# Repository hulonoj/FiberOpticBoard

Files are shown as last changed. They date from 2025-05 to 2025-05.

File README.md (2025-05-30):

# Fiber Optic Based Signal Extender

A high-speed hardware system designed to transmit and replicate electrical signals over long distances using fiber optics with minimal latency.



## Overview

This project consists of two custom PCB systems designed for high-speed signal replication across fiber:

- **Transmitter/Receiver Board:** FPGA-based PCB for protocol-agnostic electrical signal replication over fiber with ~30 ns latency.
- **Motor Controller Board:** STM32-based H-Bridge driver interfaced via I2C through the fiber optic system.

The design demonstrates a full end-to-end communication system without electrical coupling, ideal for applications where noise isolation or long-distance communication is required. This was my capstone project for my Advanced Embedded Systems course at the University of Michigan, and was worked on by a team of five. I contributed heavily and mainly to the hardware development and testing, while collaborating closely with teammates on software and system integration and validation.

## Features

- Custom fiber optic communication protocol with latency < 30 ns
- Supports arbitrary digital signal formats (protocol-agnostic)
- Isolated end-to-end data replication
- STM32 motor controller with I2C command input
- Integrated H-Bridge for direct motor control

## Photos

Fiber Optic Board mounted on top of a motor controller board.

Half-Assembled Fiber Optic Board



Schematic

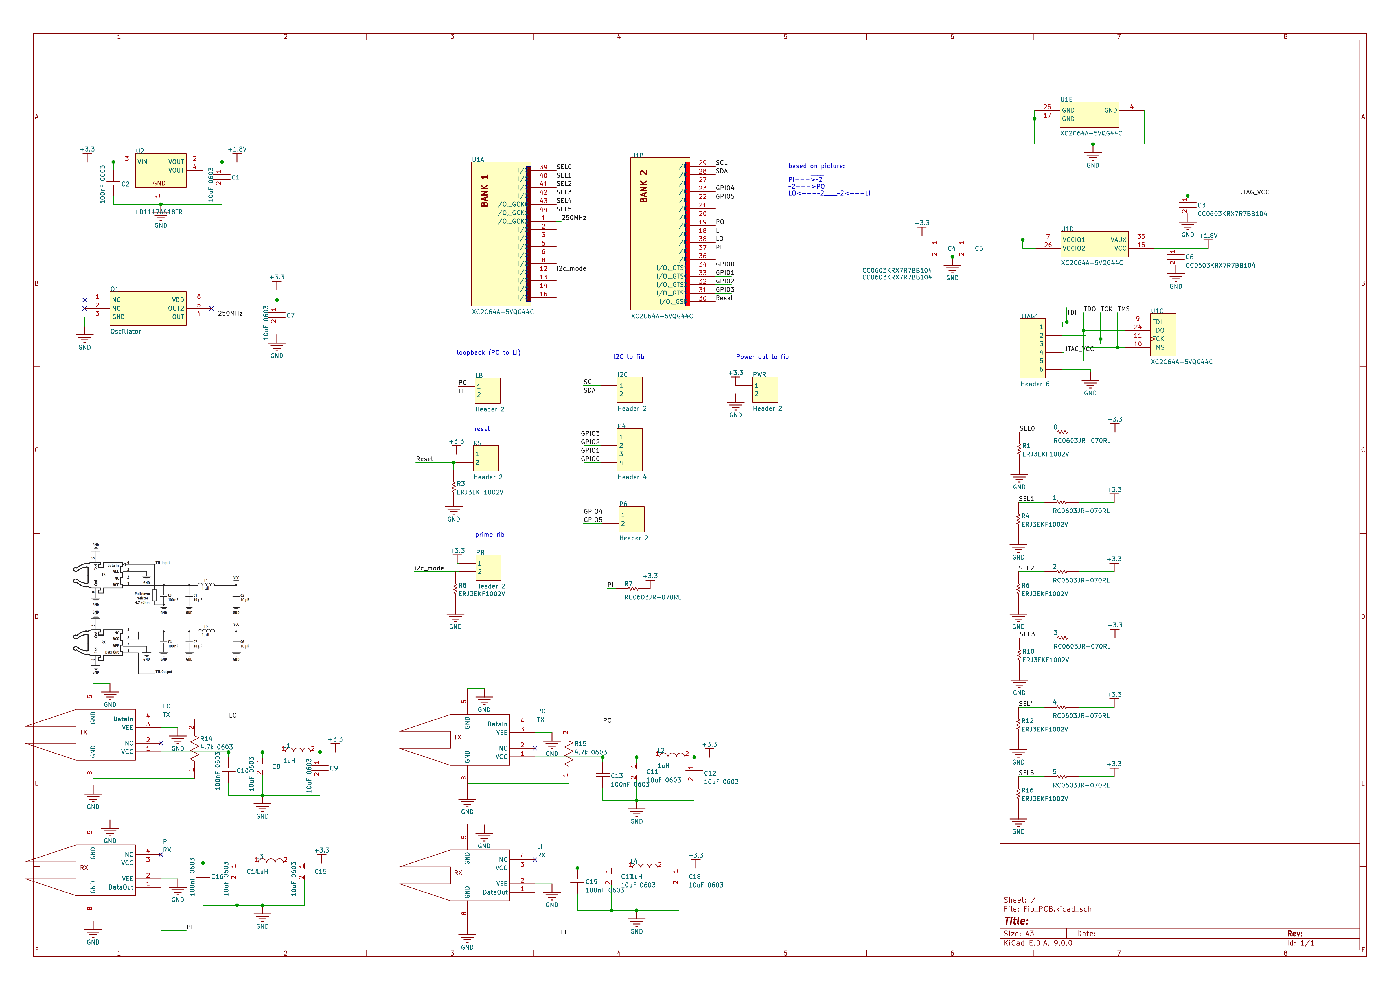
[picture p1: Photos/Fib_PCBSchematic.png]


Layout

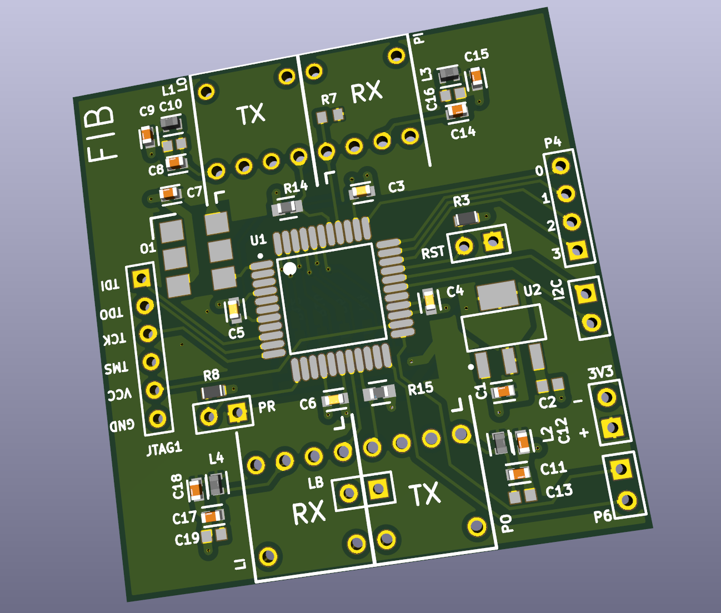
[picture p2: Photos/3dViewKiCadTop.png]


## Poster Describing Project
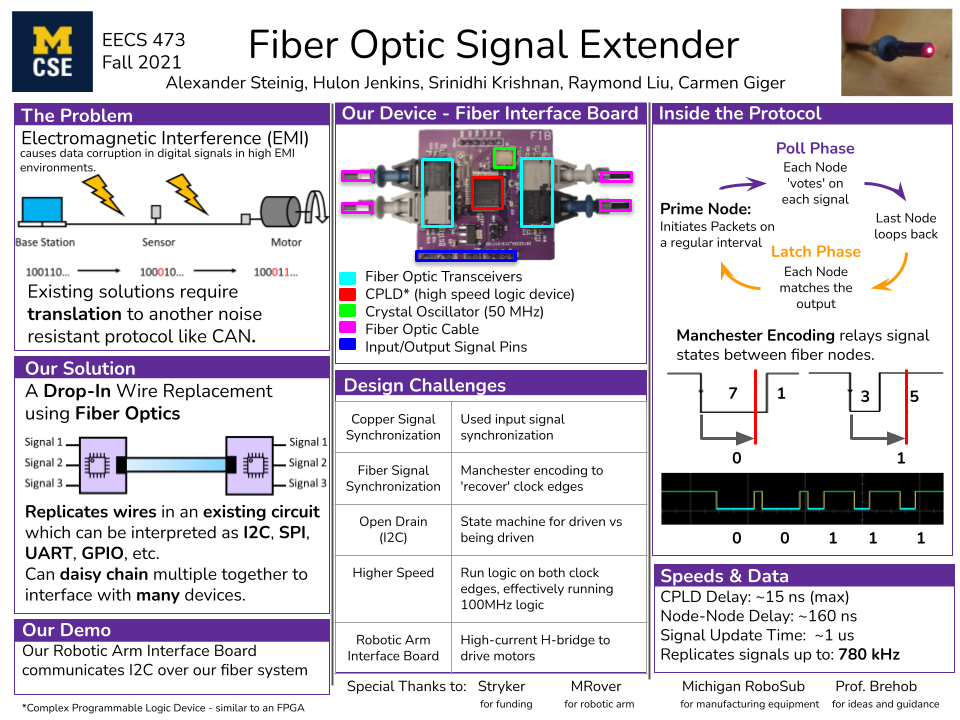
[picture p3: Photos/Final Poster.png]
Poster


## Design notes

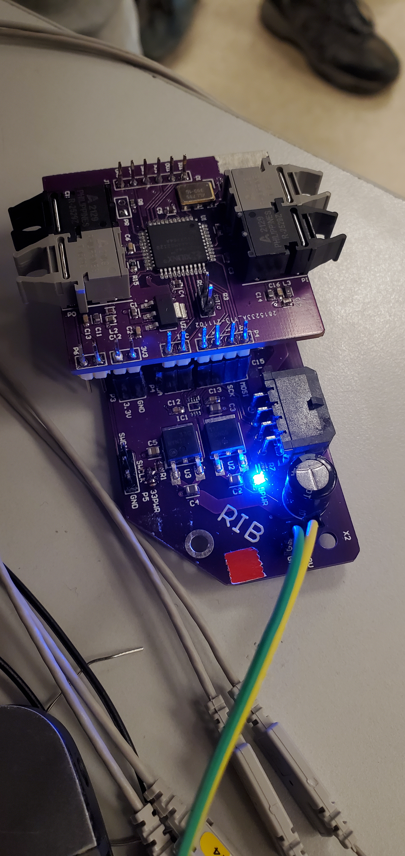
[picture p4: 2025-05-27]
Photos/FiberBoardMounted.jpg

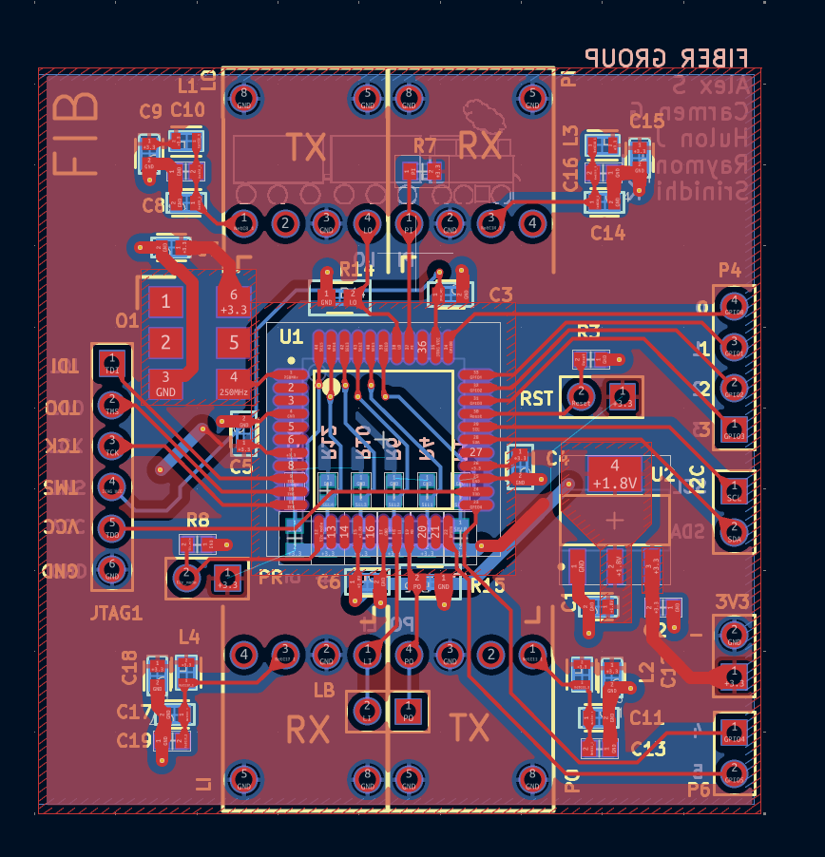
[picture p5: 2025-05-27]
Photos/LayoutKiCad.png

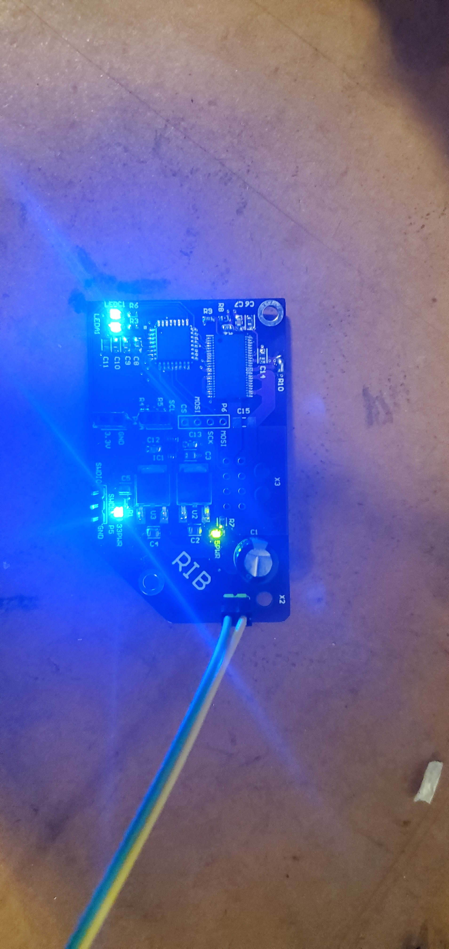
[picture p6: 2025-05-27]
Photos/MotorboardLightsOn.jpg

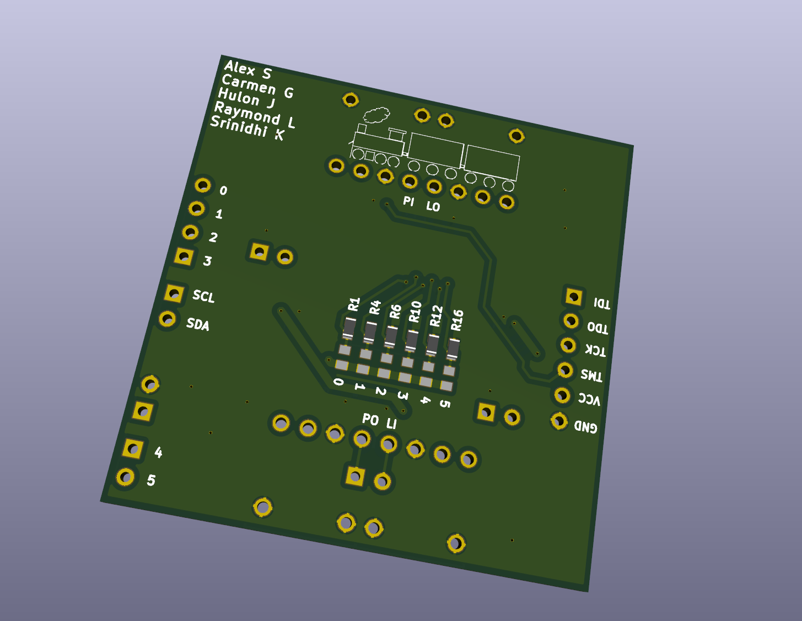
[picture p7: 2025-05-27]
Photos/3dViewKiCadBottom.png

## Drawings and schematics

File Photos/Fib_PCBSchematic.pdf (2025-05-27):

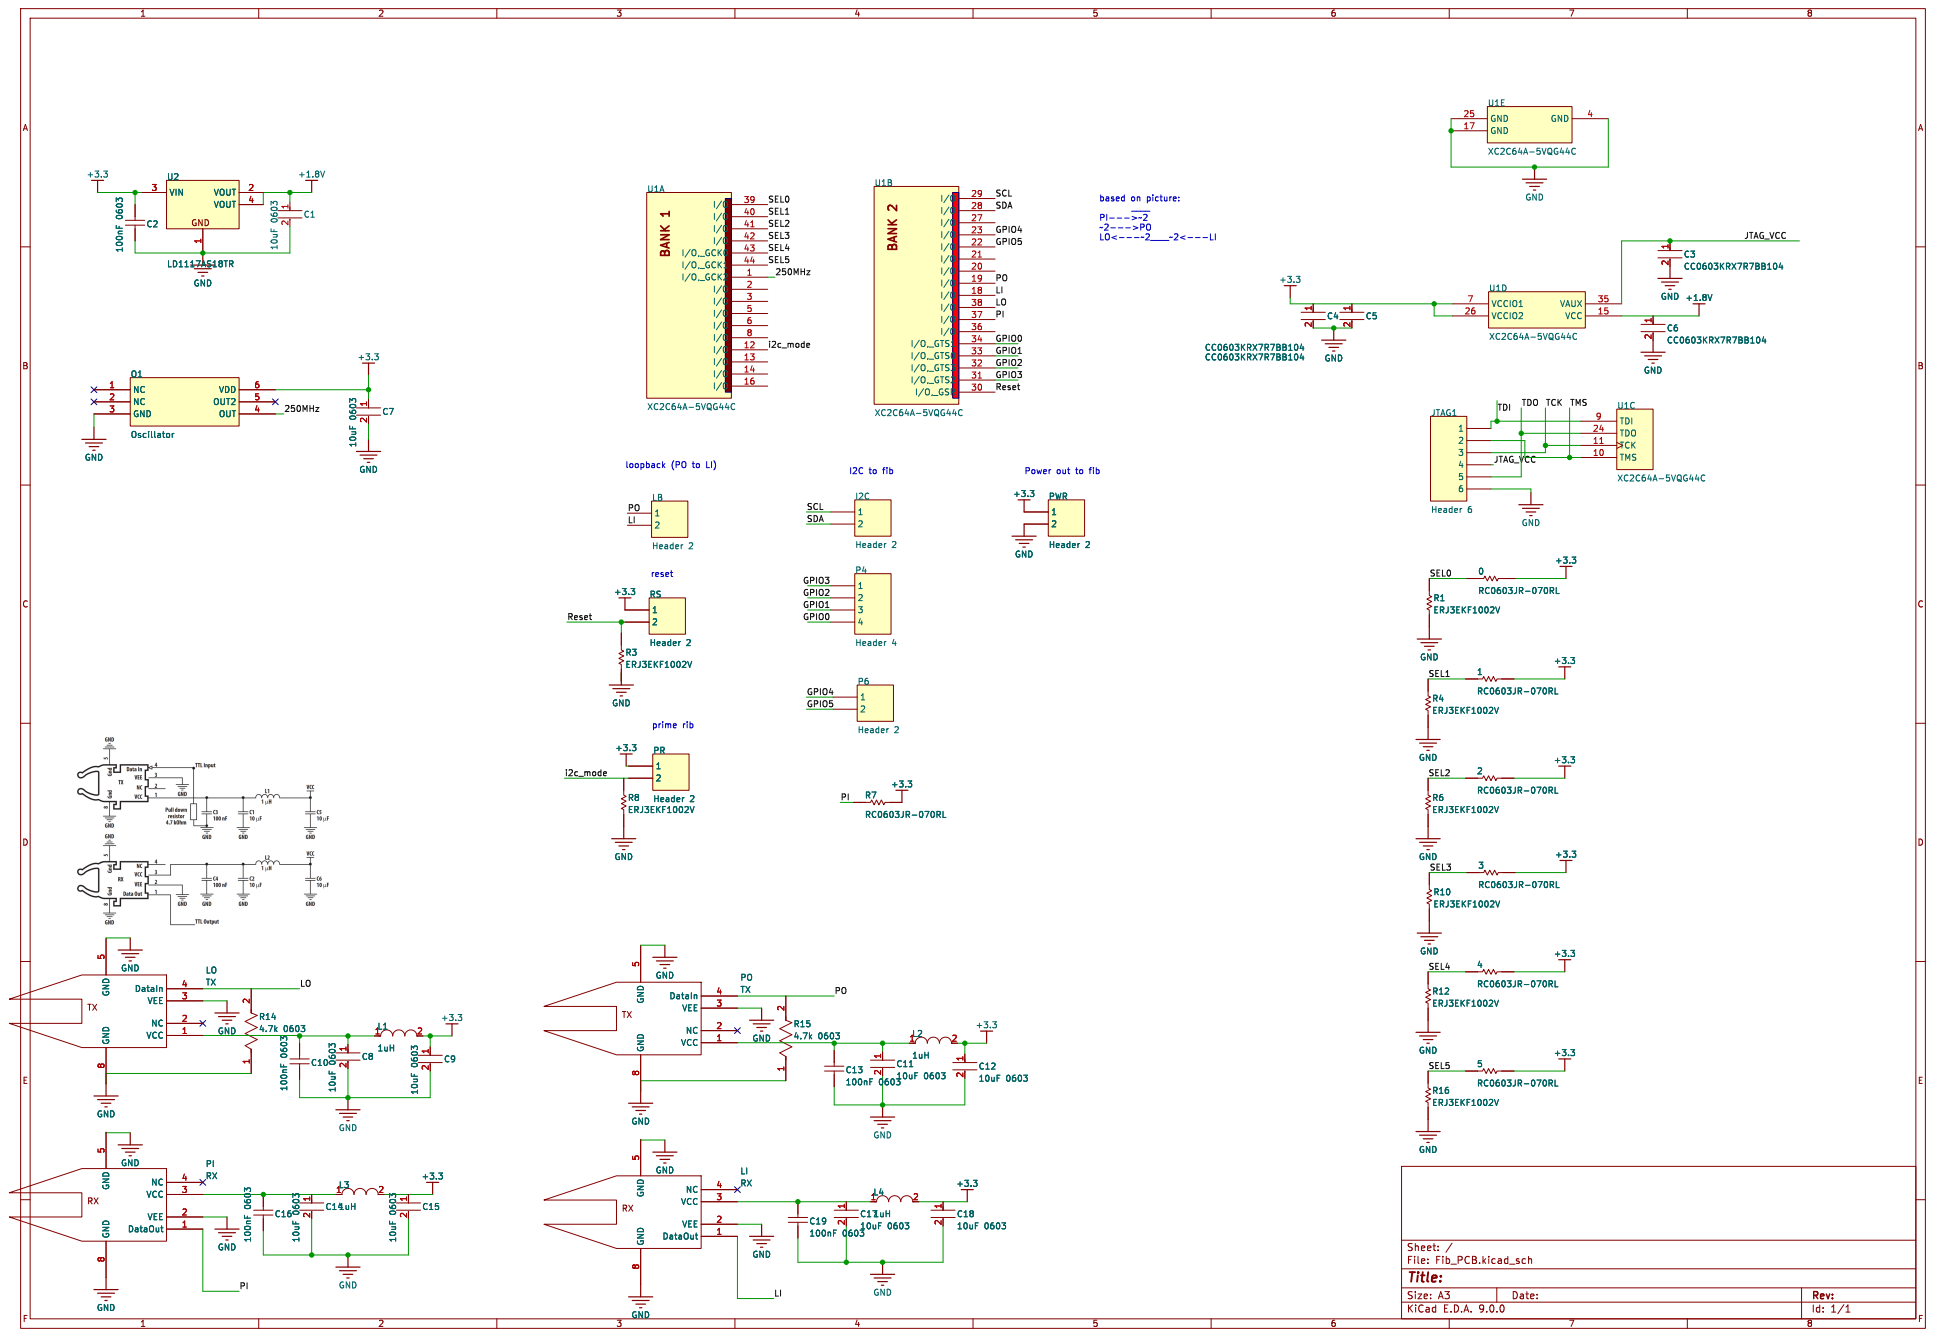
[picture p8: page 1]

1 VOUT 2 VOUT 4 GND O1 Oscillator NC 1 NC 2 GND 3 VDD 6 OUT2 5 OUT 4 GND

8 DataIn 4 VEE 3 NC 2 VCC 1 GND GND

8 DataIn 4 VEE 3 NC 2 VCC 1 PO
TX GND

8 DataIn 4 VEE 3 NC 2 VCC 1

8 NC 4 VCC 3 VEE 2 DataOut 1 GND GND

8 NC 4 VCC 3 VEE 2 DataOut 1 PI RX GND

8 NC 4 VCC 3 VEE 2 DataOut 1

8 NC 4 VCC 3 VEE 2 DataOut 1 C18

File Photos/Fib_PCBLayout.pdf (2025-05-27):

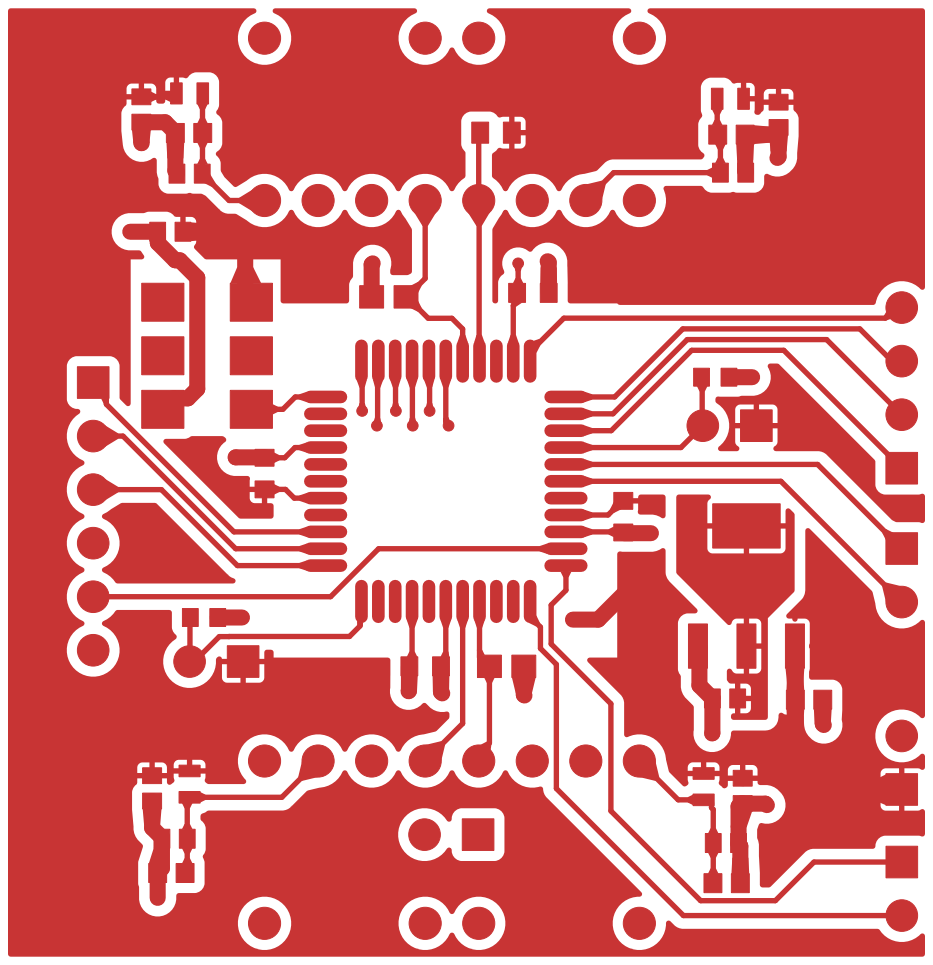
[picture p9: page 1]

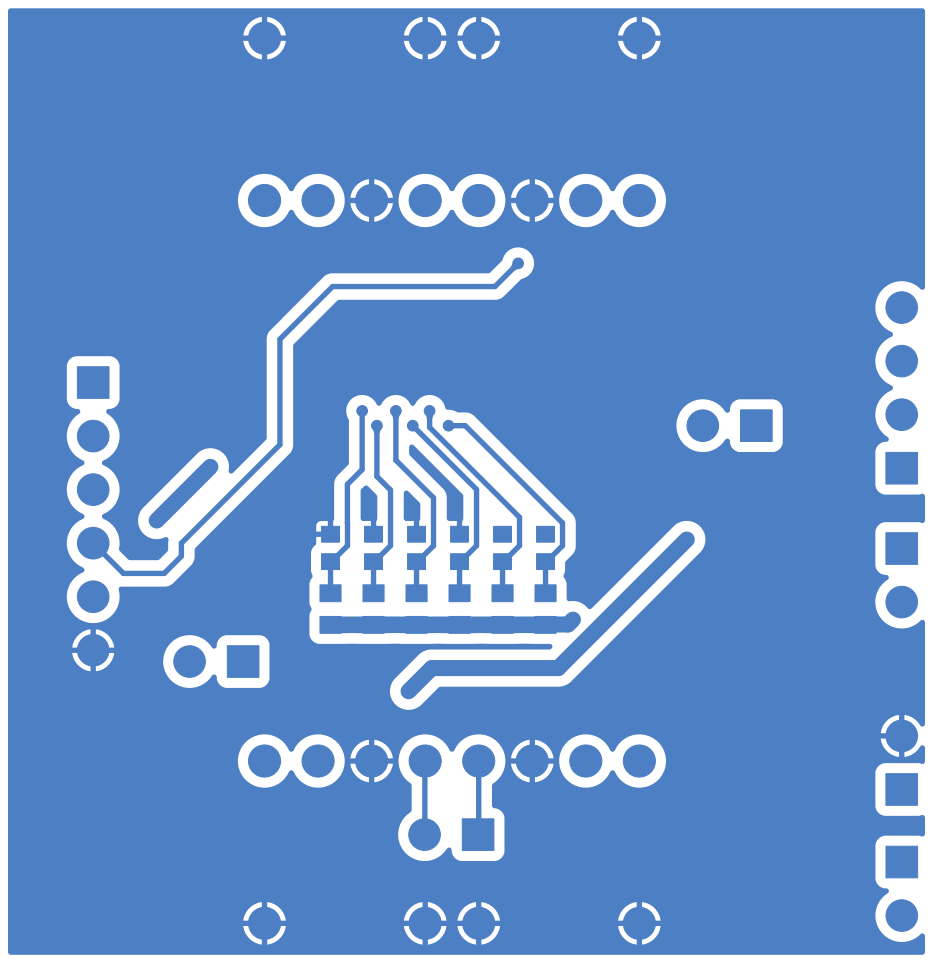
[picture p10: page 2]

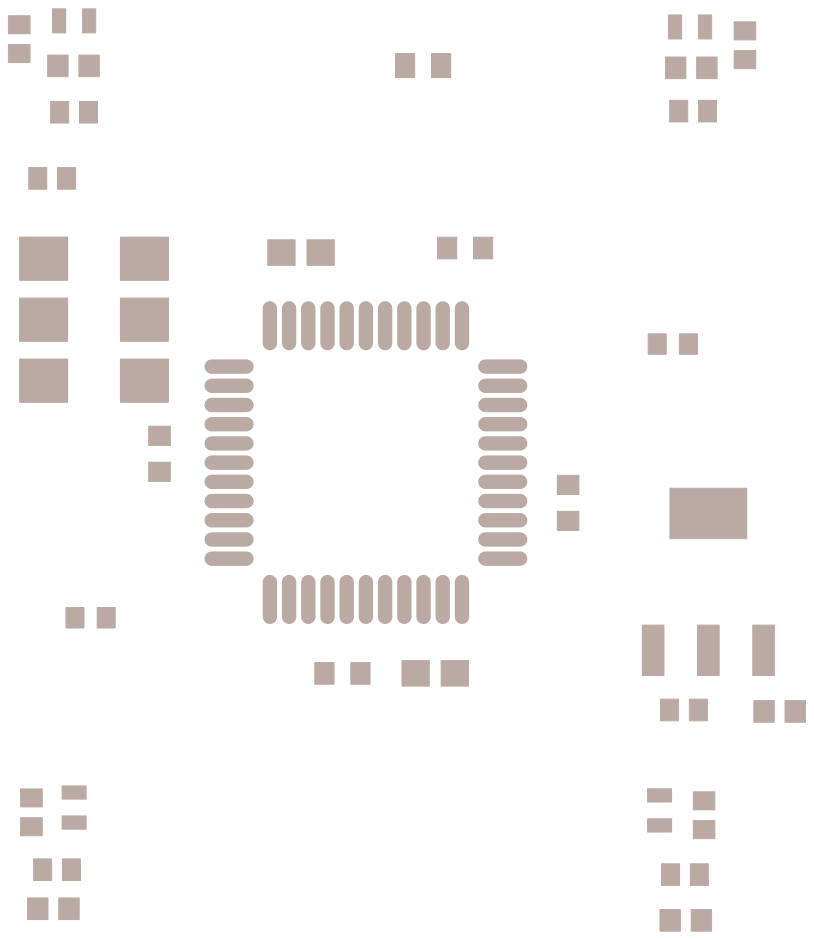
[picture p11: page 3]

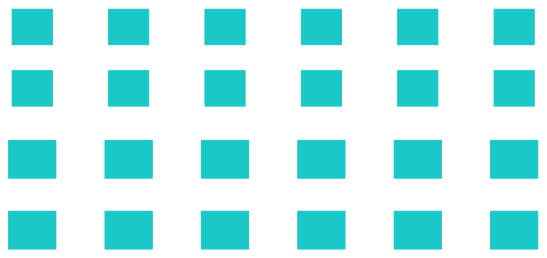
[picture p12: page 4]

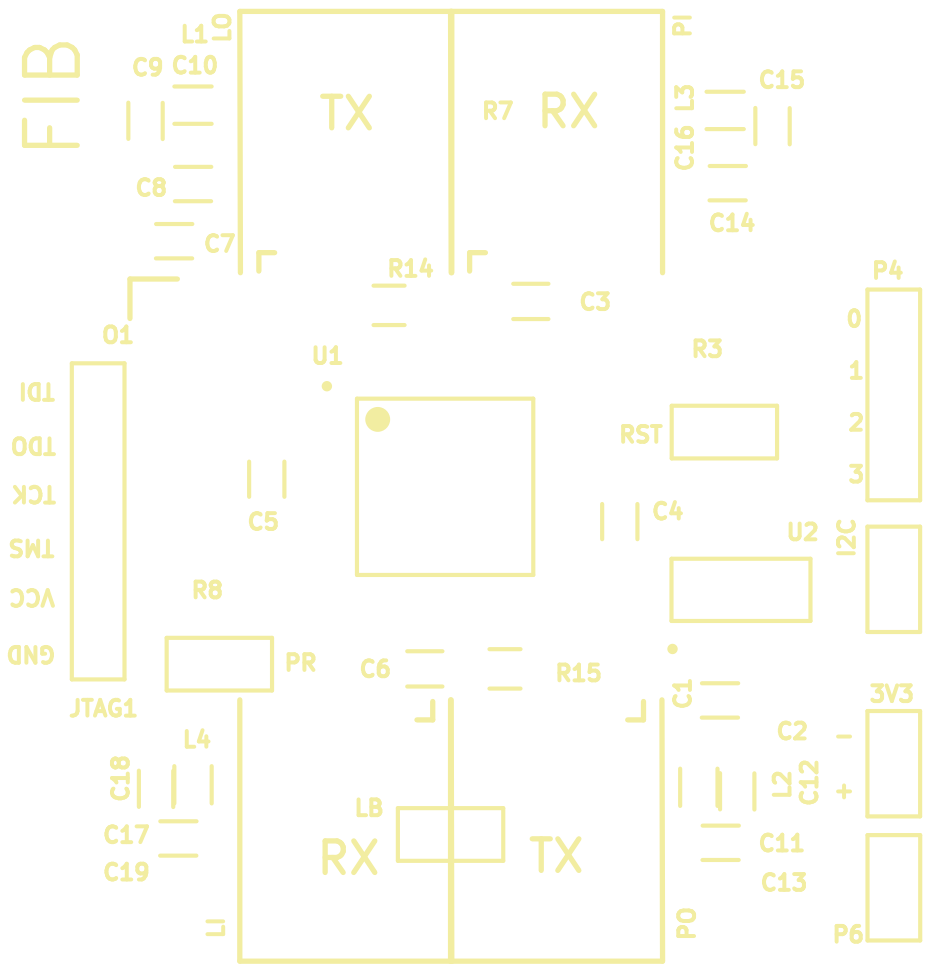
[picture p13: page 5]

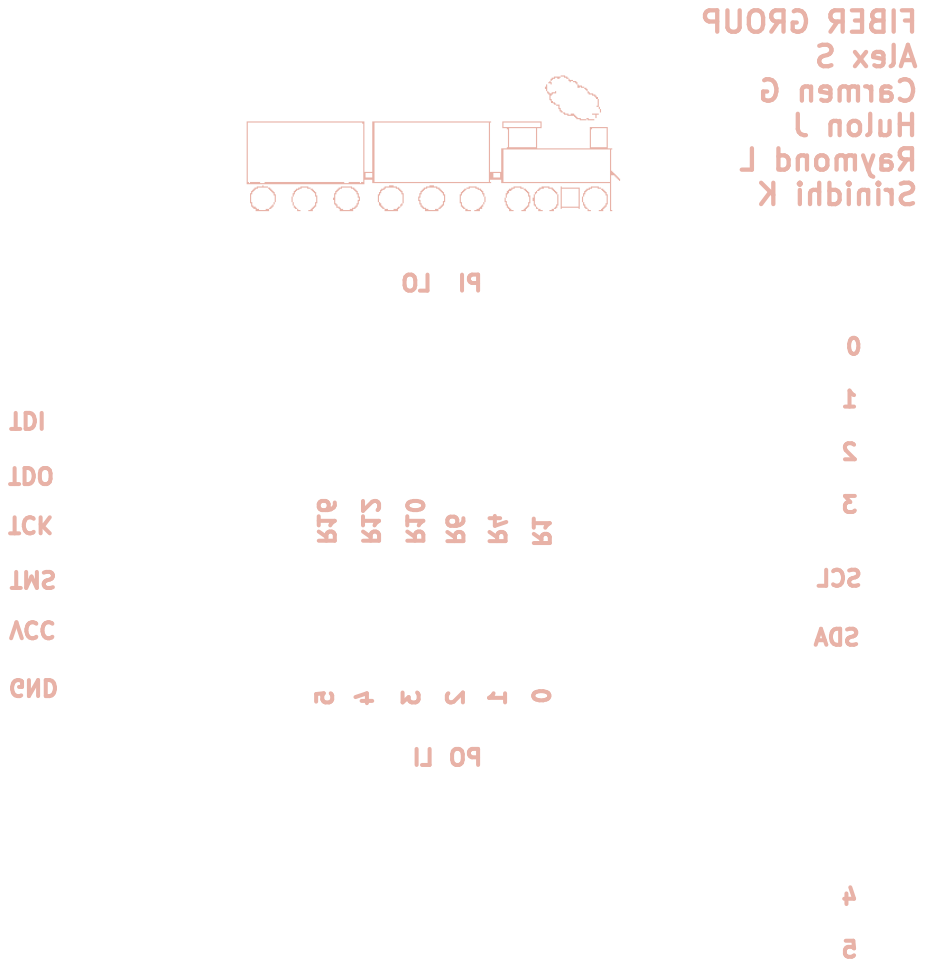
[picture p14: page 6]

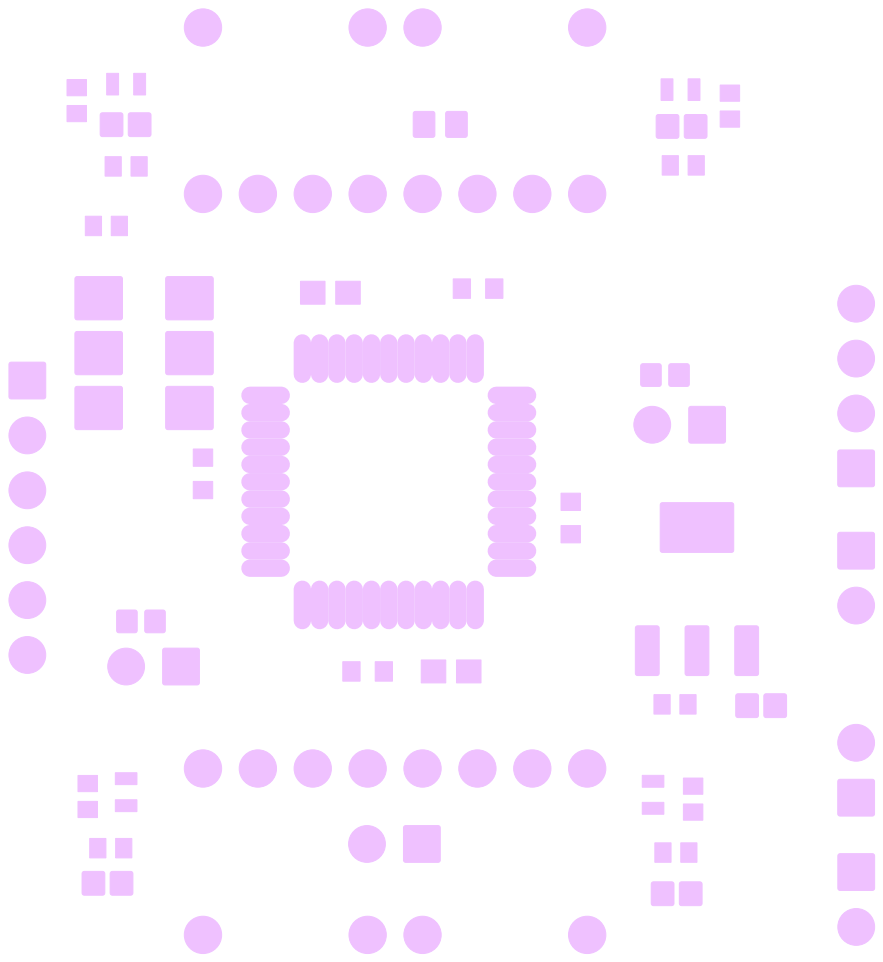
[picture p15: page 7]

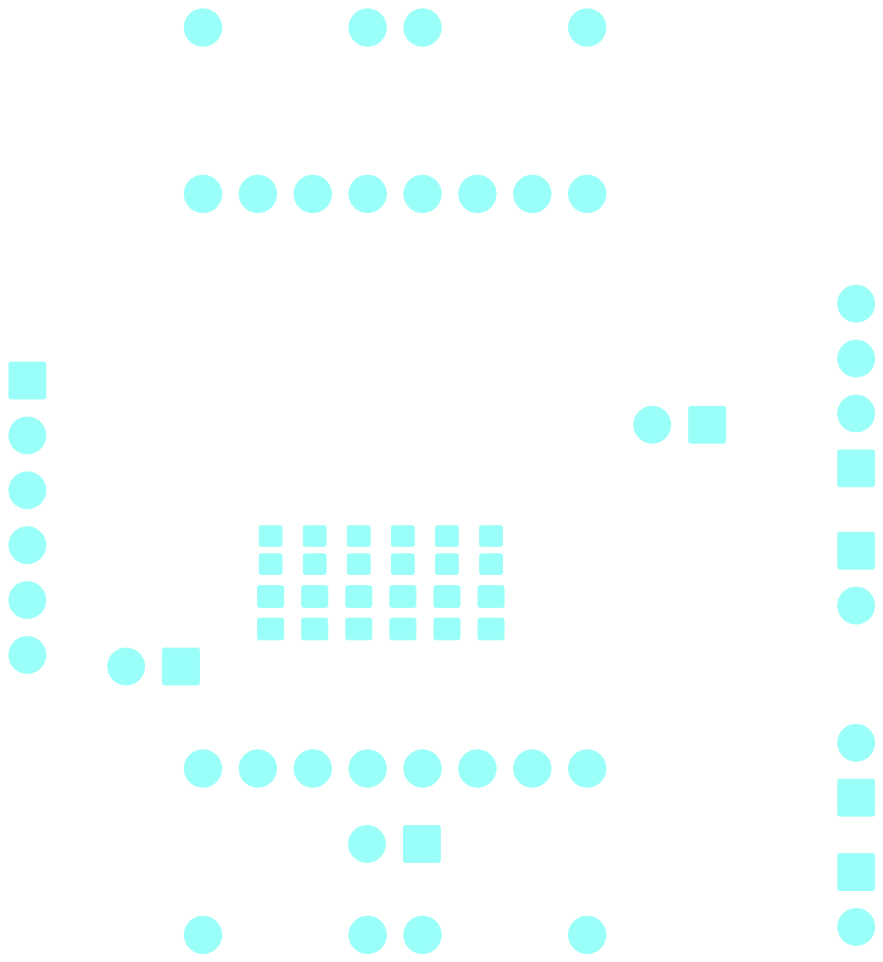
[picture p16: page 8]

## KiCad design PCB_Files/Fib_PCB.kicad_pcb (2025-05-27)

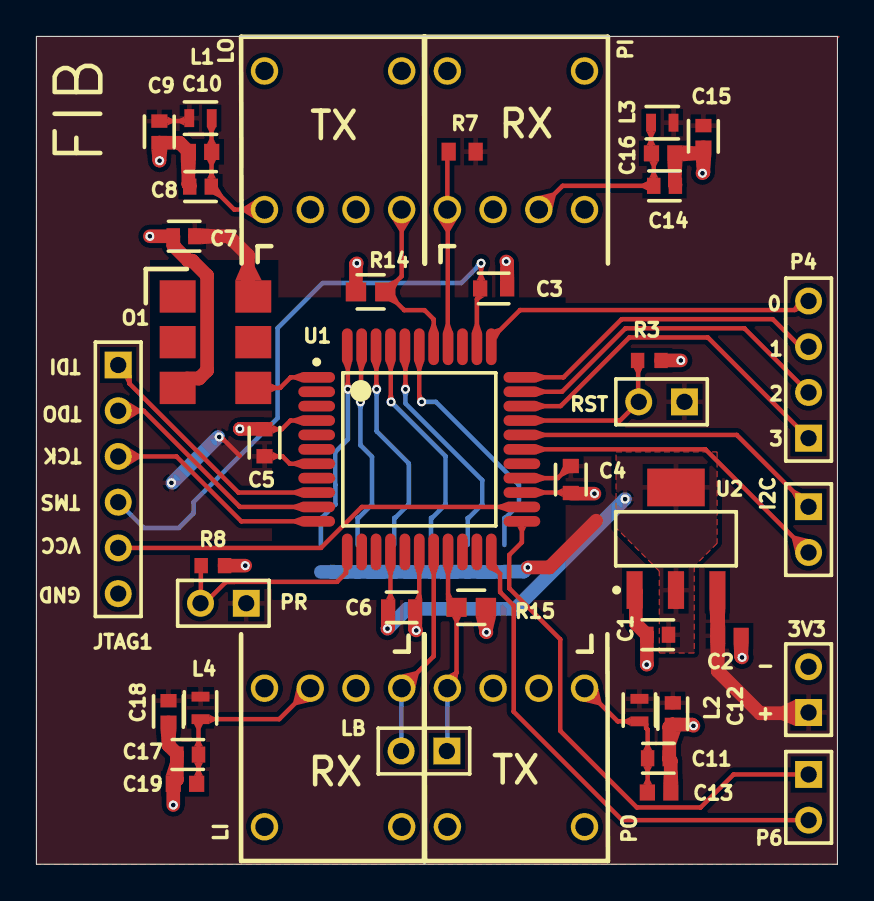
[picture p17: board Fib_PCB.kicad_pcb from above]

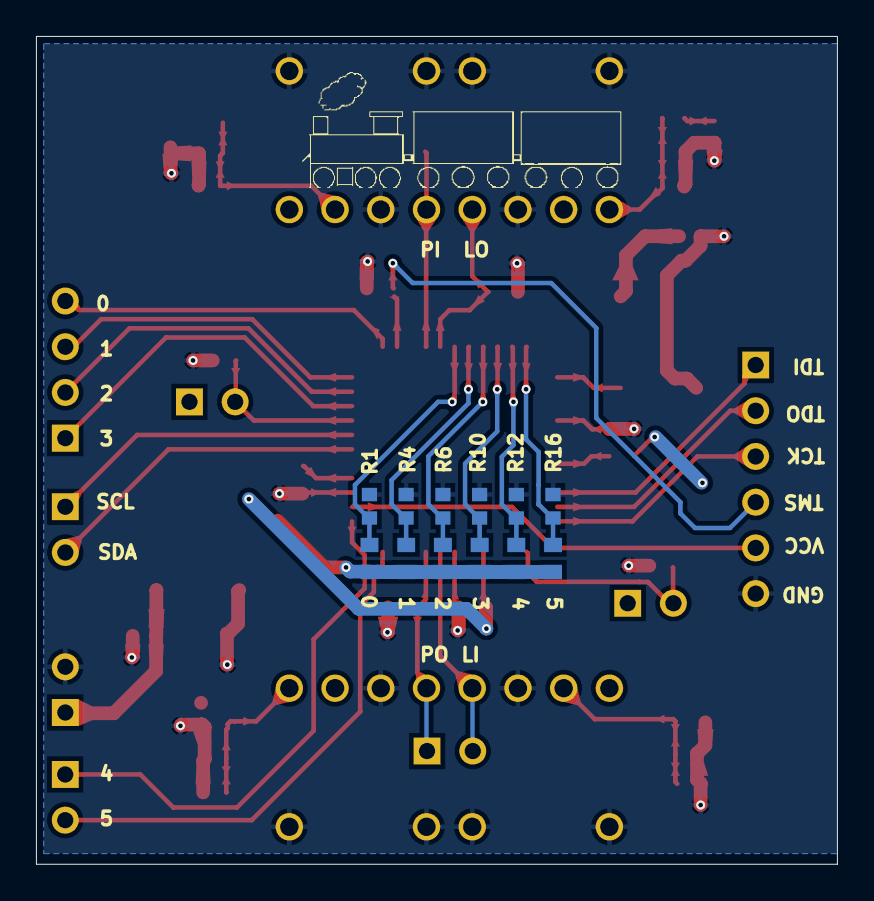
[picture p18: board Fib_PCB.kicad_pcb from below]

Board: 2 copper layers, 44.5 x 46.0 mm, 55 parts (12 on the bottom side), 33 nets.

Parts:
0, 1, 2, 3, 4, 5: RC0603JR-070RL; RESC1608X55X25ML10T15
3V3: Header 2; HDR1X2
C1, C7, C8, C9, C11, C12, C14, C15, C17, C18: 10uF 0603; FP-C0603C106M9PACTU-MFG
C2, C10, C13, C16, C19: 100nF 0603; CAPC1608X90X35LL15T15
C3, C4, C5, C6: CC0603KRX7R7BB104; FP-CC0603-DA-MFG
I2C: Header 2; HDR1X2
JTAG1: Header 6; HDR1X6
L1, L2, L3, L4: 1uH; FP-LBMF1608-0_8-0_2-MFG
LB: Header 2; HDR1X2
LI: RX; PCBComponent_1
LO: TX; PCBComponent_1
O1: Oscillator
P4: Header 4; HDR1X4
P6: Header 2; HDR1X2
PI: RX; PCBComponent_1
PO: TX; PCBComponent_1
PR: Header 2; HDR1X2
R1, R3, R4, R6, R8, R10, R12, R16: ERJ3EKF1002V; RESC1609X55X30LL15T15
R7: RC0603JR-070RL; RESC1608X55X25ML10T15
R14, R15: 4.7k 0603; FP-CRCW0603-e3-IPC_A
RST: Header 2; HDR1X2
U1: XC2C64A-5VQG44C; VQG44_M
U2: LD1117AS18TR; SOT-223_L

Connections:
250MHz: O1.4, U1.1
+1.8V: C1.1, C6.1, U1.15, U2.2, U2.4
+3.3: 0.2, 1.2, 2.2, 3.2, 3V3.1, 4.2, 5.2, C2.2, C4.1, C5.1, C7.1, C9.1, C12.1, C15.1, C18.1, L1.2, L2.2, L3.2, L4.2, O1.6, PR.1, R7.2, RST.1, U1.7, U1.26, U2.3
GND: 3V3.2, C1.2, C2.1, C3.2, C4.2, C5.2, C6.2, C7.2, C8.2, C9.2, C10.1, C11.2, C12.2, C13.1, C14.2, C15.2, C16.1, C17.2, C18.2, C19.1, JTAG1.6, LI.2, LI.5, LI.8, LO.3, LO.5, LO.8, O1.3, PI.2, PI.5, PI.8, PO.3, PO.5, PO.8, R1.1, R3.1, R4.1, R6.1, R8.1, R10.1, R12.1, R14.1, R15.1, R16.1, U1.4, U1.17, U1.25, U2.1
GPIO0: P4.4, U1.34
GPIO1: P4.3, U1.33
GPIO2: P4.2, U1.32
GPIO3: P4.1, U1.31
GPIO4: P6.1, U1.23
GPIO5: P6.2, U1.22
JTAG_VCC: C3.1, JTAG1.4, U1.35
LI: LB.2, LI.1, U1.18
LO: LO.4, R14.2, U1.38
NetC8_1: C8.1, C10.2, L1.1, LO.1
NetC11_1: C11.1, C13.2, L2.1, PO.1
NetC14_1: C14.1, C16.2, L3.1, PI.3
NetC17_1: C17.1, C19.2, L4.1, LI.3
PI: PI.1, R7.1, U1.37
PO: LB.1, PO.4, R15.2, U1.19
Reset: R3.2, RST.2, U1.30
SCL: I2C.1, U1.29
SDA: I2C.2, U1.28
SEL0: 0.1, R1.2, U1.39
SEL1: 1.1, R4.2, U1.40
SEL2: 2.1, R6.2, U1.41
SEL3: 3.1, R10.2, U1.42
SEL4: 4.1, R12.2, U1.43
SEL5: 5.1, R16.2, U1.44
TCK: JTAG1.3, U1.11
TDI: JTAG1.1, U1.9
TDO: JTAG1.5, U1.24
TMS: JTAG1.2, U1.10
i2c_mode: PR.2, R8.2, U1.12
